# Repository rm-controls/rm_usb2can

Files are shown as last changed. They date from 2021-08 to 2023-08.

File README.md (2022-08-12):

# rm_usb2can

&nbsp;&nbsp;&nbsp;&nbsp;

English/[中文](https://github.com/rm-controls/rm_usb2can/blob/main/README_CN.md)

***

### Brief Introduction

&nbsp;&nbsp;&nbsp;&nbsp;The purpose of this project is to provide [Intel® NUC](https://www.intel.com/content/www/us/en/products/details/nuc.html) and other x86 device with a CAN (Controller Area Network) peripheral interface. Since NUC and most x86 device does not have simple peripheral interfaces such as SPI (Serial Peripheral Interface), it is impossible to use SPI to can chips such as MCP2515. Therefore, the project is developed based on the open source solution [candleLight](https://github.com/candle-usb/candleLight_fw/tree/master) on GitHub, and STM32F072CBT6 is used as the main control chip to realize the function of USB (Universal Serial Bus) to can. STM32F072CBT6 has USB full speed peripherals and can peripherals that can work at the same time. It is packaged as QFP64 (Quad Flat Package) and is an excellent solution.The following figure shows the physical connection between Intel NUC and usb2can.

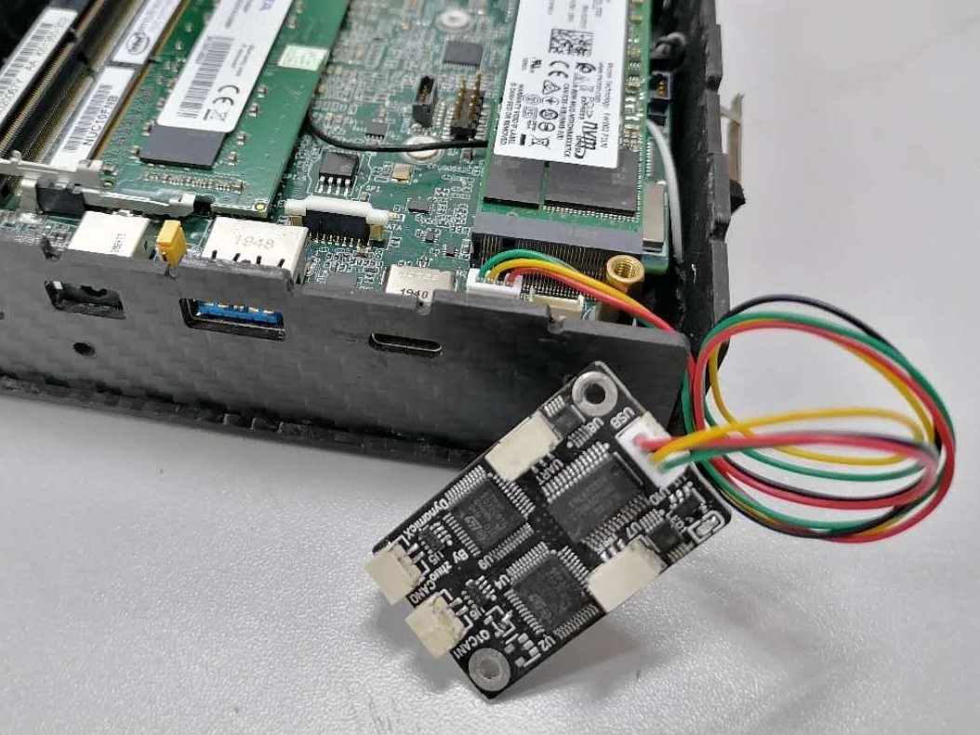
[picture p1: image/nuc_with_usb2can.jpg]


***

### Develop Tools

+ EDA Tool: Altium Designer 20.0.13
+ Compiler: gcc-arm-none-eabi  8-2019-q3-update
+ Programming Tool: STM32CubeProgrammer v2.6.0

***

### Directory Structure

+ bom: three different versions of usb2can material forms.
+ candlelight: the repository of GitHub's open source solution [candleLight](https://github.com/candle-usb/candleLight_fw/tree/master).
+ circuit: circuit schematic diagram and PCB source file designed with Altium designer.
+ gerber: three different versions of usb2can manufacturing documents.
+ image: picture in readme.
+ firmware.bin: Compiled program binaries.

**Note: the PCB and schematic diagram under the circuit folder are example circuits, which are directly used to manufacture products with production results other than those shown in the figure. If you want to directly reproduce the graphic version, please use the production file under the gerber folder.**

***

### Circuit Design

#### Key Points Of Schematic Design

&nbsp;&nbsp;&nbsp;&nbsp;USB HUB Circuit Design: since the whole vehicle needs at least two can buses to ensure the integrity of the data packet returned by the motor, we use GL850G as the USB HUB chip to realize the scheme of USB one driving four. In addition, we also use Schmidt trigger to realize the power on sequence to ensure that the enumeration sequence of USB devices is consistent after each power on.

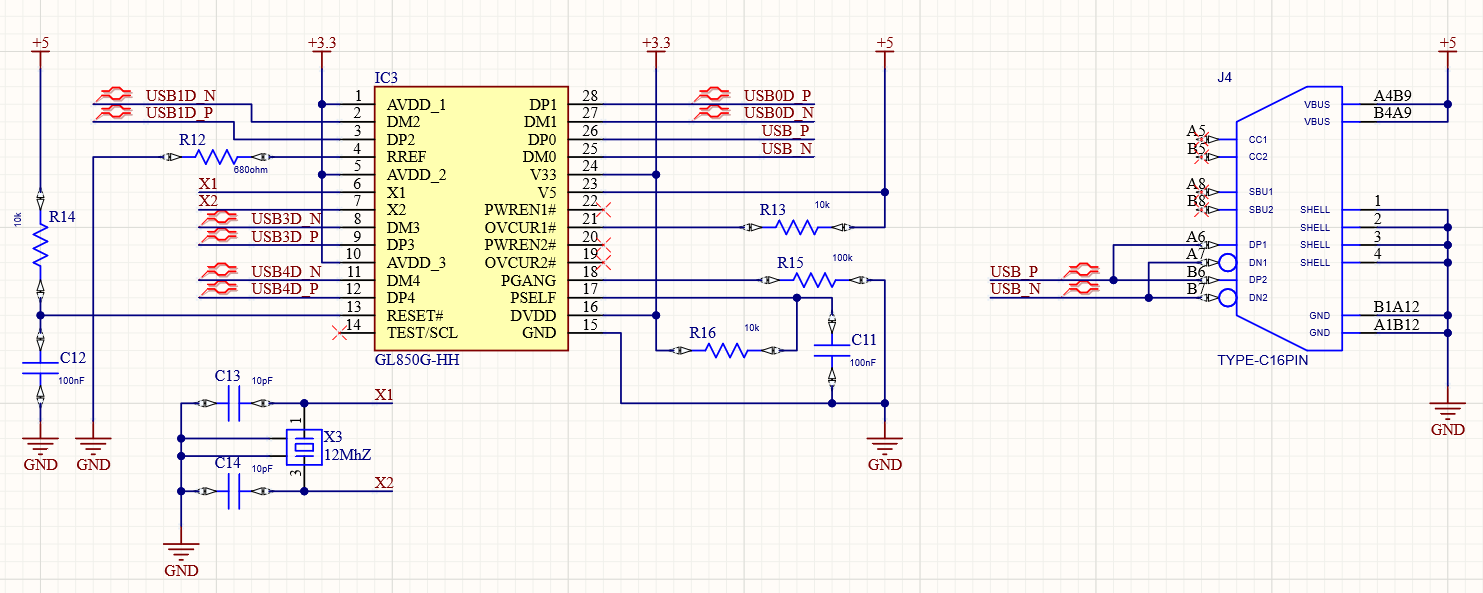
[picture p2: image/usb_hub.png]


&nbsp;&nbsp;&nbsp;&nbsp;USB To CAN Circuit Design: use STM32F072CBT6 to realize the function of USB to can. The can level conversion chip adopts MAX3051EKA chip, which uses 3.3V power supply and is packaged as SOT23-8 (Small Outline Transistor), which provides the basis for PCB miniaturization. The purpose of R6 and R7 resistors in the figure is to change the boot mode of STM32, so that STM32 can switch between DFU (Device Firmware Upgrade) burning mode and flash mode by changing the short circuit mode of R6 and R7, so as to facilitate firmware burning.

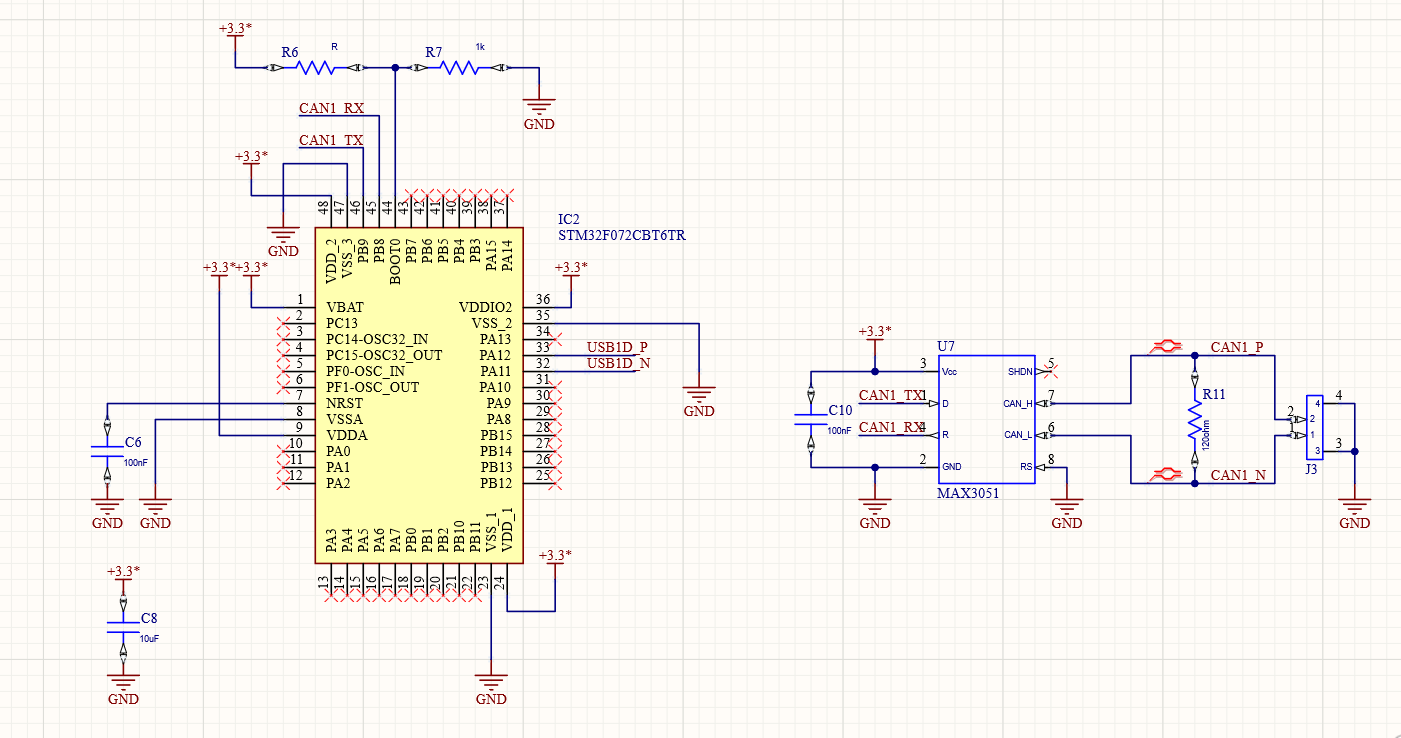
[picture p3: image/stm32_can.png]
stm32_can


#### Key Points Of PCB Layout And Wiring

1. All USB buses need to be set as differential pairs, and the wiring rules of differential signals shall be strictly followed during wiring.
2. All CAN buses need to be set as differential pairs, and the wiring rules of differential signals shall be strictly followed during wiring.
3. The bottom of crystal oscillator and resonant capacitor should be hollowed out without copper.
4. The power line width shall be greater than 0.3mm as far as possible to ensure that the power track does not collapse.

***

### Circuit Making

&nbsp;&nbsp;&nbsp;&nbsp;We provide three different versions of Gerber files for production: [two-way CAN + UART + DBUS](https://github.com/rm-controls/rm_usb2can/tree/main/gerber/2CAN%2BUART%2BDBUS), [four-way CAN](https://github.com/rm-controls/rm_usb2can/tree/main/gerber/4CAN), [UART + DBUS](https://github.com/rm-controls/rm_usb2can/tree/main/gerber/UART%2BDBUS).The circuits of these three versions are designed with two-layer PCB, with an area of about 20 * 30MM. You can directly submit the packaged Gerber file to a manufacturer (such as [jlc](https://www.jlc.com/#)) for production.

&nbsp;&nbsp;&nbsp;&nbsp;You can find the BOM (Bill Of Material) table corresponding to the board [here](https://github.com/rm-controls/rm_usb2can/tree/main/bom) and weld the components to the fabricated PCB according to this table. After welding, please carefully check whether there is residual solder between the pins, which will lead to short circuit of the circuit board. At the same time, you should also check whether there is false soldering of the pins.

&nbsp;&nbsp;&nbsp;&nbsp;After welding, use a multimeter to check whether there is a short circuit between 5V power interface and GND, and whether there is a short circuit between 3.3V power output and GND. When the above situation does not occur, connect the board to the USB port of the computer. At this time, you should see that the power indicator on the board is on, and the computer can recognize the USB HUB chip.

**Note: do not weld the up / down resistance used to switch STM32 download mode at the same time, as it may cause a short circuit between the power supply and GND!**

***

### Firmware Programming

&nbsp;&nbsp;&nbsp;&nbsp;You can [click here](https://github.com/rm-controls/rm_usb2can/releases/download/firmware_v1_0/candleLight.bin) to download the compiled firmware, or follow the [candlelight documentation](https://github.com/candle-usb/candleLight_fw/tree/master#building) to compile firmware by yourself. Finally, you will get the .bin file. We use [STM32CubeProgrammer](https://www.st.com/en/development-tools/stm32cubeprog.html) to burn the firmware into STM32 through USB. The steps to download firmware are shown below:

1. Remove the pull-down resistance of BOOT0 pin of STM32 and weld the pull-up resistance.
2. Connect the board to the USB port of the computer and open STM32CubeProgrammer.
3. Click the three buttons shown in the following figure in STM32CubeProgrammer to search for available STM32 devices.

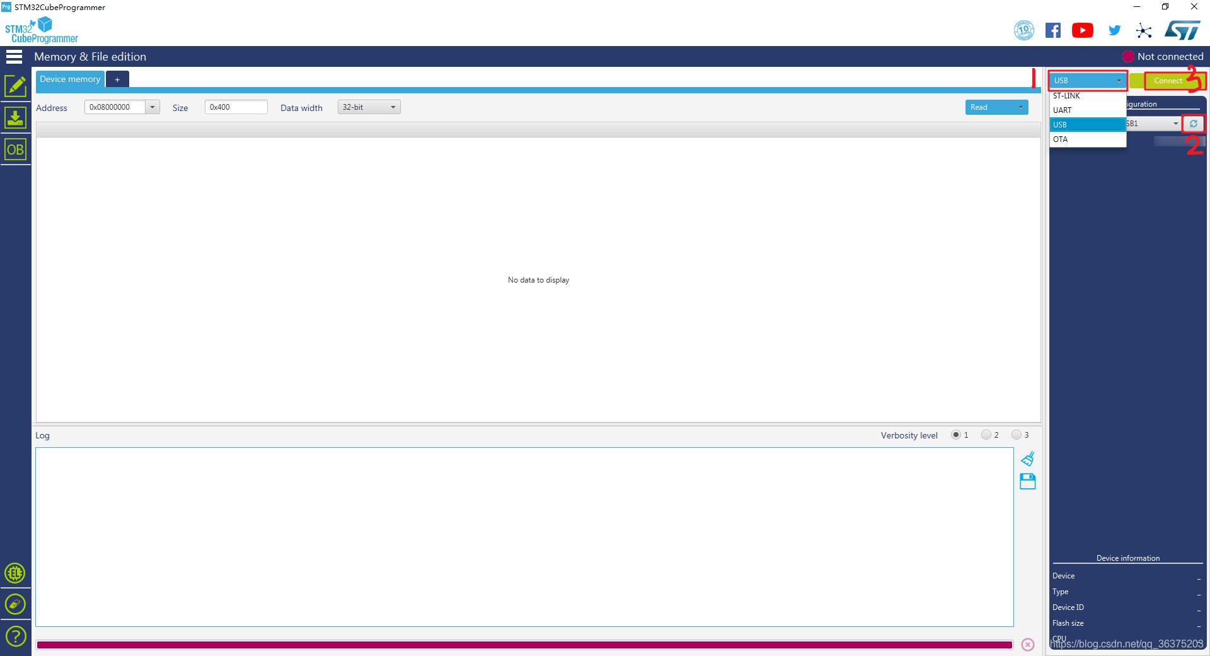
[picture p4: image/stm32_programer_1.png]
stm32_programer_1


4. After successful connection, click the "Read" button to read the firmware and select the prepared firmware.

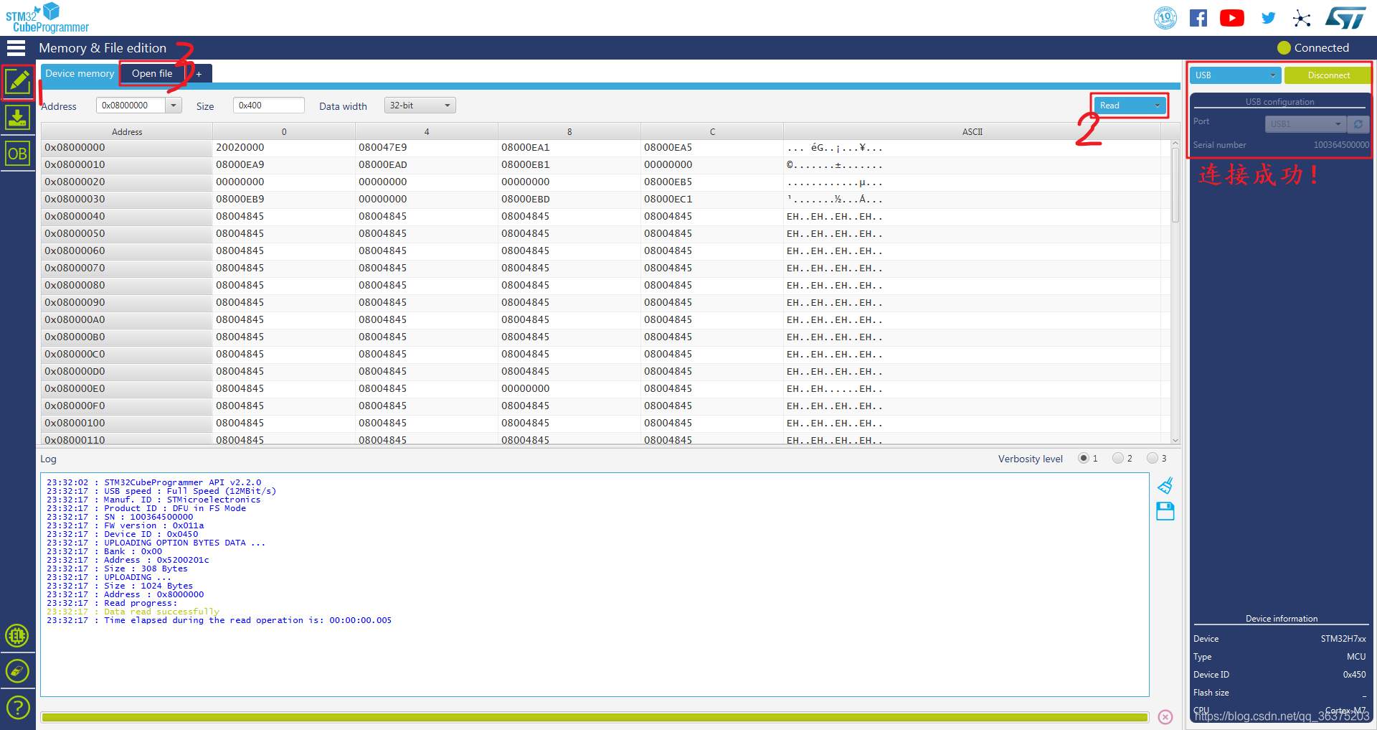
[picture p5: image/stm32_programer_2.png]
stm32_programer_2


5. Click "Download" to download the firmware. After the download is successful, you can see the successful information.

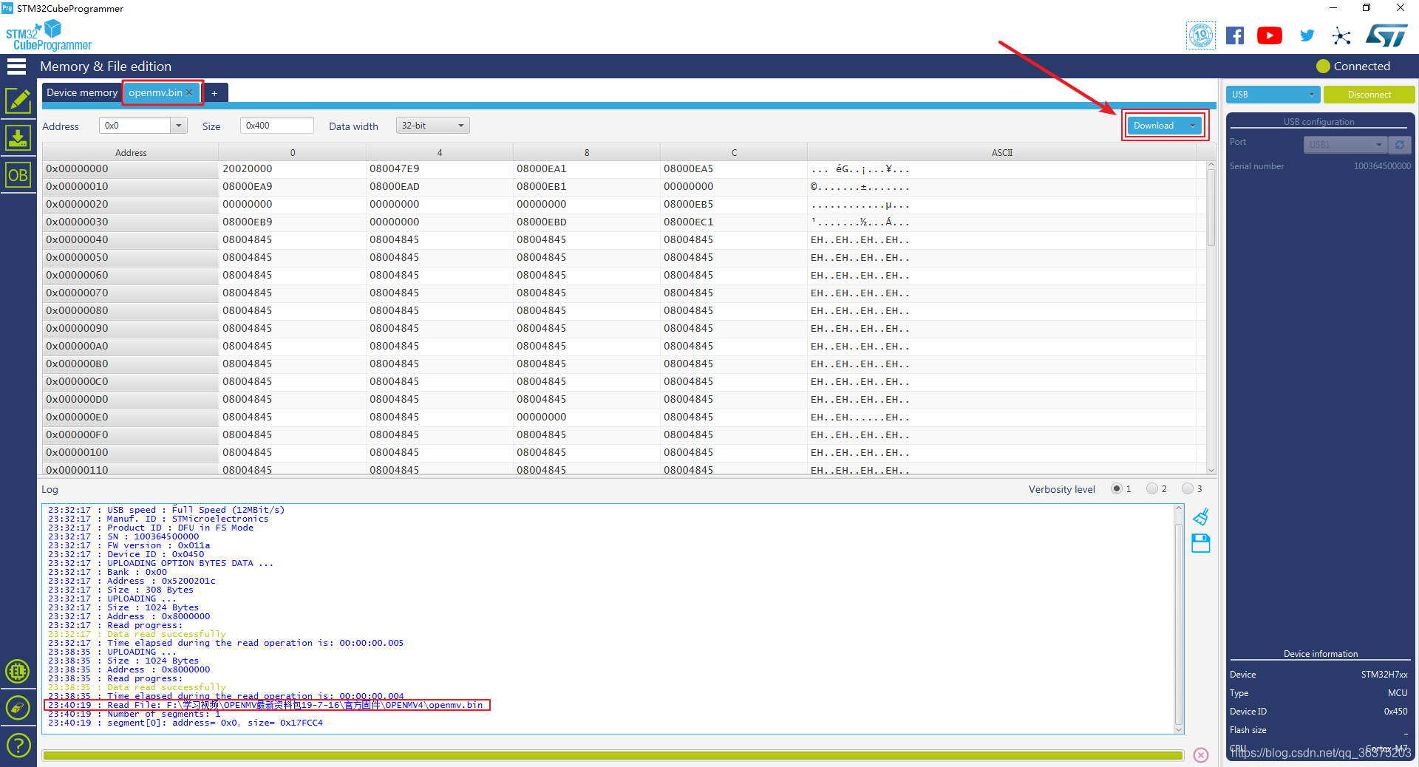
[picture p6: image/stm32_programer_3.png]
stm32_programer_3


6. Remove the pull-up resistance of BOOT0 pin on STM32 and weld the pull-down resistance. Power on again at this time, and the firmware will start running on STM32.

***

### Test Features On Ubuntu

1. Install dependent packages:

```bash
$ sudo apt-get update && sudo apt-get -y upgrade
$ sudo apt-get install -y can-utils net-tools
```

2. Check whether can device is detected:

```bash
$ ifconfig -a
# If a device with can name is found in the list, it means that the device can be recognized
```

3. Connect the two can ports with a **straight line** to facilitate loop back test.
4. Initialize CAN0 and CAN1 devices with a bit rate of 1Mbits:

```bash
$ sudo ip link set can0 up type can bitrate 1000000
$ sudo ip link set can1 up type can bitrate 1000000
```

5. Open a new terminal to monitor the information received by can0:

```bash
$ candump can0
```

6. Sending information using can1 in a terminal:

```bash
$ cansend can1 200#5A5A5A5A5A5A5A5A
```

If you can see the following information from can1 in the terminal monitoring can0, it indicates that the communication is successful and the module works normally.

```bash
can0 200 [8] 5A 5A 5A 5A 5A 5A 5A 5A
```

***

### License

The source code is released under a [MIT License](https://github.com/rm-controls/rm_usb2can/blob/main/LICENSE).

**Affiliation：DynamicX<br>
Maintainer：YanzhenZhu, 2208213223@qq.com**

The product has been tested under Ubuntu 18.04 and 20.04. This is research code, expect that it changes often and any fitness for a particular purpose is disclaimed.

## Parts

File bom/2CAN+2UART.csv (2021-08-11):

ID | Name | Designator | Footprint | Quantity | Manufacturer Part | Manufacturer | Supplier | Supplier Part | Price | Pins
1 | 10uF | C1,C2,C3,C4,C20 | C0402 | 5 | CL05A106MQ5NUNC | SAMSUNG | LCSC | C15525 | 0.044 | 2
2 | 100nF | C5,C6,C7,C8,C9,C10,C11,C12,C13,C14,C15,C16,C17,C18,C21,C23 | C0402 | 16 | CL05B104KO5NNNC | SAMSUNG | LCSC | C1525 | 0.0071 | 2
3 | 18pF | C19,C22 | C0402 | 2 | 0402CG180J500NT | FH | LCSC | C1549 | 0.0079 | 2
4 | GH1.25_2P | CAN1,CAN2 | GH1.25_2P_卧贴 | 2 |  | Changjiang Connectors | LCSC | C225125 | 0.4487 | 2
5 | PESD5V0F1BL,315 | D1,D2,D3,D4,D6,D7,D8 | SOD-882_L1.0-W0.6-BI | 7 | PESD5V0F1BL,315 | Nexperia | LCSC | C45961 | 0.2763 | 2
6 | PESD12V0F1BL,315 | D5 | SOD-882_L1.0-W0.6-BI | 1 | PESD5V0F1BL,315 | Nexperia | LCSC | C45961 | 0.2763 | 2
7 | ESDR0502NMUTBG | D9 | UDFN-6_L1.2-W1.0-P0.40-BL | 1 | ESDR0502NMUTBG | ON Semicon | LCSC | C327480 | 0.99 | 6
8 | GH1.25-3P-COLOR | DBUS,UART | GH1.25-3P-COLOR | 2 | A2008WR-S-3P | Changjiang Connectors | LCSC | C273131 | 0.751 | 5
9 | 19-217/BHC-ZL1M2RY/3T | LED1 | LED0603-R-RD | 1 | 19-217/BHC-ZL1M2RY/3T | EVERLIGHT | LCSC | C72041 | 0.0992 | 2
10 | m2.5 | M1,M2 | M2.5 螺丝 | 2
11 | AO3400A | Q1,Q2 | SOT-23-3_L2.9-W1.6-P1.90-LS2.8-BR | 2 | AO3400A | AOS | LCSC | C20917 | 1.185 | 3
12 | S8050_C2146 | Q3 | SOT-23-3_L3.0-W1.7-P0.95-LS2.9-BR | 1 | S8050 | CJ | LCSC | C2146 | 0.1411 | 3
13 | 10K | R1,R2,R3,R10,R15,R16,R18 | R0402 | 7 | 0402WGF1002TCE | UniOhm | LCSC | C25744 | 0.004 | 2
14 | 0 | R4,R11 | R0402 | 2 | 0402WGF0000TCE | UniOhm | LCSC | C17168 | 0.0046 | 2
15 | 10k | R5,R13 | R0402 | 2 | 0402WGF0000TCE | UniOhm | LCSC | C17168 | 0.0046 | 2
16 | 1K | R6 | R0402 | 1 | 0402WGF1001TCE | UniOhm | LCSC | C11702 | 0.0042 | 2
17 | 120 | R7,R8 | R0402 | 2 | 0402WGF1200TCE | UniOhm | LCSC | C25079 | 0.0045 | 2
18 | 4.7K | R9 | R0402 | 1 | 0402WGF4701TCE | UniOhm | LCSC | C25900 | 0.0038 | 2
19 | 47K | R12 | R0402 | 1 | 0402WGF4702TCE | UniOhm | LCSC | C25792 | 0.0046 | 2
20 | 680 | R14 | R0402 | 1 | 0402WGF6800TCE | UniOhm | LCSC | C25130 | 0.0038 | 2
21 | 100K | R17 | R0402 | 1 | 0402WGF1003TCE | UniOhm | LCSC | C25741 | 0.004 | 2
22 | 0R | R19 | R0402 | 1 | 0402WGF6800TCE | UniOhm | LCSC | C25130 | 0.0038 | 2
23 | HX9193-33GB | U1 | SOT-23-5_L3.0-W1.7-P0.95-LS2.8-BR | 1 | HX9193-33GB | hengjiaxing | LCSC | C296123 | 0.1654 | 4
24 | 74LVC1G17 | U2,U3 | SOT-23-5 | 2 |  |  |  |  |  | 4
25 | STM32F072CBT6 | U4,U9 | LQFP-48_L7.0-W7.0-P0.50-LS9.0-BL | 2 | STM32F072CBT6 | STMicroelectronics | LCSC | C81720 | 144.77 | 15
26 | MAX3051EKA+T | U5,U6 | SOT-23-8_L3.0-W1.7-P0.65-LS2.8-TL | 2 | MAX3051EKA+T | MAXIM | LCSC | C112005 | 9.59 | 7
27 | CH340E | U7 | MSOP-10_L3.0-W3.0-P0.50-LS5.0-BL | 1 | CH340E | WCH | LCSC | C99652 | 3.7 | 6
28 | CH340E | U8 | MSOP-10_L3.0-W3.0-P0.50-LS5.0-BL | 1 | CH340E | WCH | LCSC | C99652 | 3.7 | 7
29 | GL850G-HHY22 | U10 | SSOP-28_L10.2-W5.3-P0.65-LS7.8-BL | 1 | GL850G-HHY22 | GENESYS | LCSC | C136617 | 5.23 | 24
30 | MX1.25-4P | USB | MX1.25-4P | 1 |  |  |  |  |  | 4
31 | 12MHz | X1 | OSC-SMD_4P-L3.2-W2.5-BL | 1 | X322512MSB4SI | YXC | LCSC | C9002 | 0.59 | 4

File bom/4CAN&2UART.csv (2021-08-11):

Comment | Description | Designator | Footprint | Quantity | value
C | 无极性贴片电容 | C1, C2, C3, C4, C11, C18, C19, C20 | C 0402_L | 8 | 10uF
C | 无极性贴片电容 | C5, C6, C7, C8, C12, C13, C14, C17, C21, C22, C23, C24, C25, C26, C27, C28, C29, C30, C31, C32, C33, C34, C35, C36, C37, C38, C39, C40, C41, C42, C43, C44 | C 0402_L | 32 | 100nF
C | 无极性贴片电容 | C9, C10 | C 0402_L | 2 | 18pF
C | 无极性贴片电容 | C15, C16 | C 0402_L | 2 | 10pF
GH1.25-2P | 2P接插件 | CAN1, CAN2, CAN3, CAN4 | GH1.25-2P | 4
ESDR0502NMUTBG | USB2.0 ESD保护 | D1, D7 | UDFN-6 | 2
LED-SMD | 贴片LED | D2, D8 | LED 0603R | 2
PESD12VV1BL | 双向ESD，5V关断电压 | D3 | SOD-882 | 1
PESD5V0F1BL | 双向ESD，5V关断电压 | D4, D5, D6, D9, D10, D11, D12, D13, D14, D15, D16 | SOD-882 | 11
GH1.25-3P | 3P接插件 | J1, J2 | GH1.25-3P | 2
M2.5 | 铜柱孔 | M1, M2, M3, M4, M5, M6 | M3 125X200 | 6
AO3400A | N沟道MOS管 | Q1, Q3, Q4, Q5 | SOT23-3N | 4
S8050 | 高频放大-NPN型 | Q2 | SOT23-3N | 1
R | 贴片电阻 | R1, R5, R7, R8, R12, R14, R15, R16, R22, R23, R30, R31 | R 0402_L | 12 | 10k
R | 贴片电阻 | R2, R10 | R 0402_L | 2 | 1k
R | 贴片电阻 | R3, R11 | R 0402_L | 2 | 680R
R | 贴片电阻 | R4 | R 0402_L | 1 | 4.7k
R | 贴片电阻 | R6, R13 | R 0402_L | 2 | 100k
R | 贴片电阻 | R9 | R 0402_L | 1 | 47k
R | 贴片电阻 | R17 | R 0402_L | 1 | 51k
R | 贴片电阻 | R18 | R 0402_L | 1 | 270k
R | 贴片电阻 | R19, R26, R27, R34 | R 0402_L | 4 | 120R
R | 贴片电阻 | R20, R21, R24, R25, R28, R29, R32, R33 | R 0402_L | 8 | 0R
HX9193-33G | LDO 3V3 | U1, U6 | SOT23-5N | 2
74LVC1G17 |  | U2, U8, U9, U10 | SOT23-5N | 4
GL850G | USB-HUB 1拖4 | U3, U7 | SSOP28_N | 2
CH340E | USB转串口 | U4, U5 | MSOP10_N | 2
MAX3051 | CAN收发器 | U11, U14, U15, U18 | SOT23-8N | 4
STM32F072CBT6 |  | U12, U13, U16, U17 | LQFP48 7X7_N | 4
MX1.25-4P | 4P接插件 | USB, USB1 | MX 1.25-WI-4P | 2
12M | 4脚无源晶振 | X1, X2 | OSC 3225-4P | 2

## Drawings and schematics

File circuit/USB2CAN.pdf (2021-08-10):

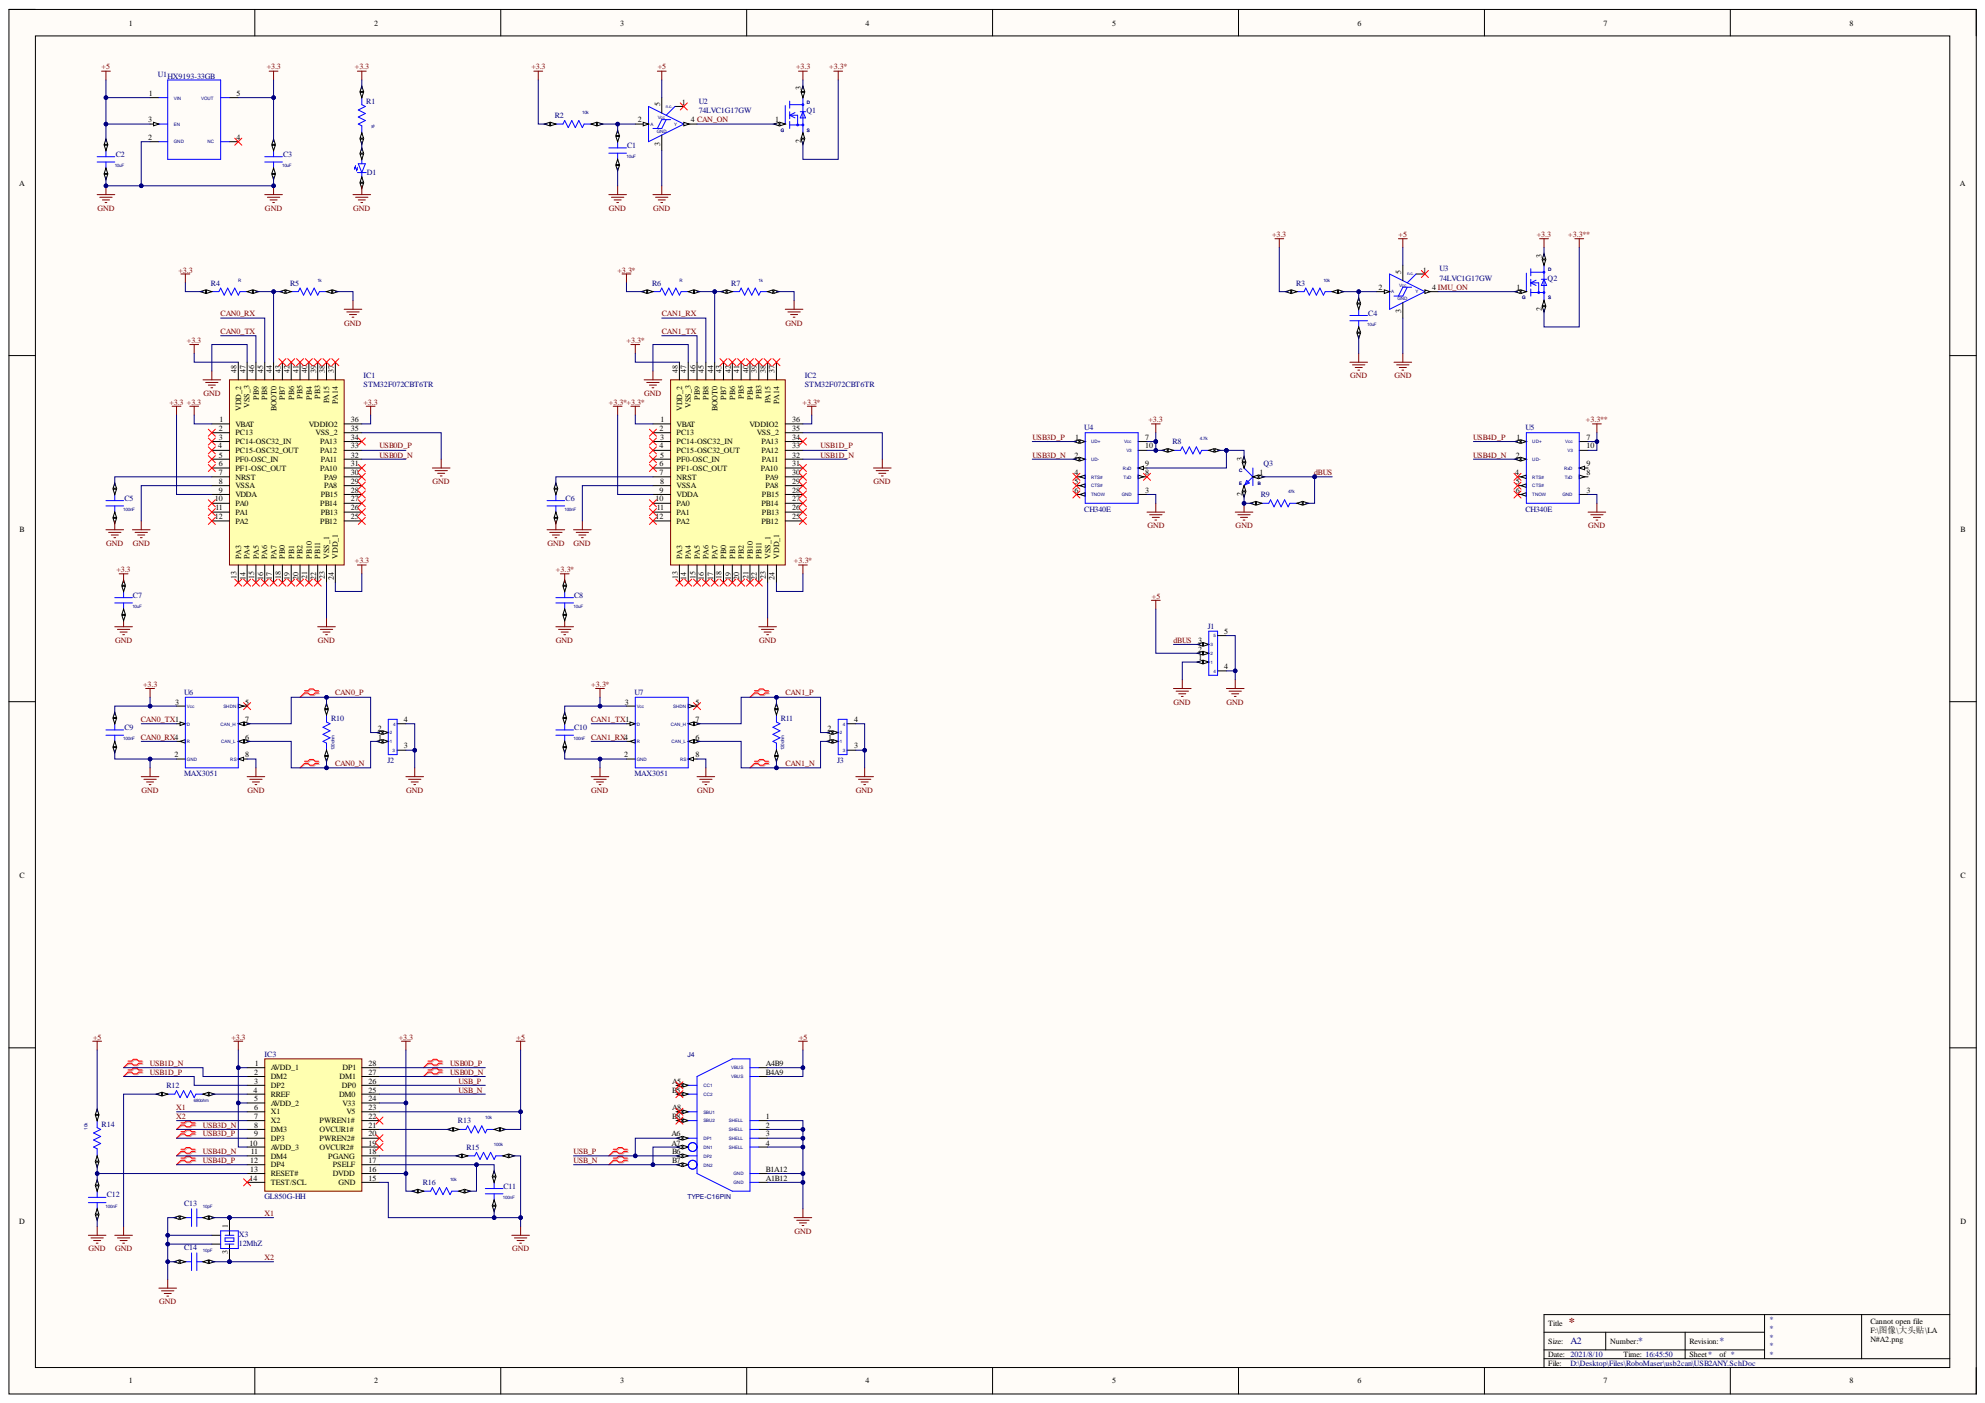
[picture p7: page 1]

D:\Desktop\Files\RoboMaser\usb2can\USB2ANY.SchDoc

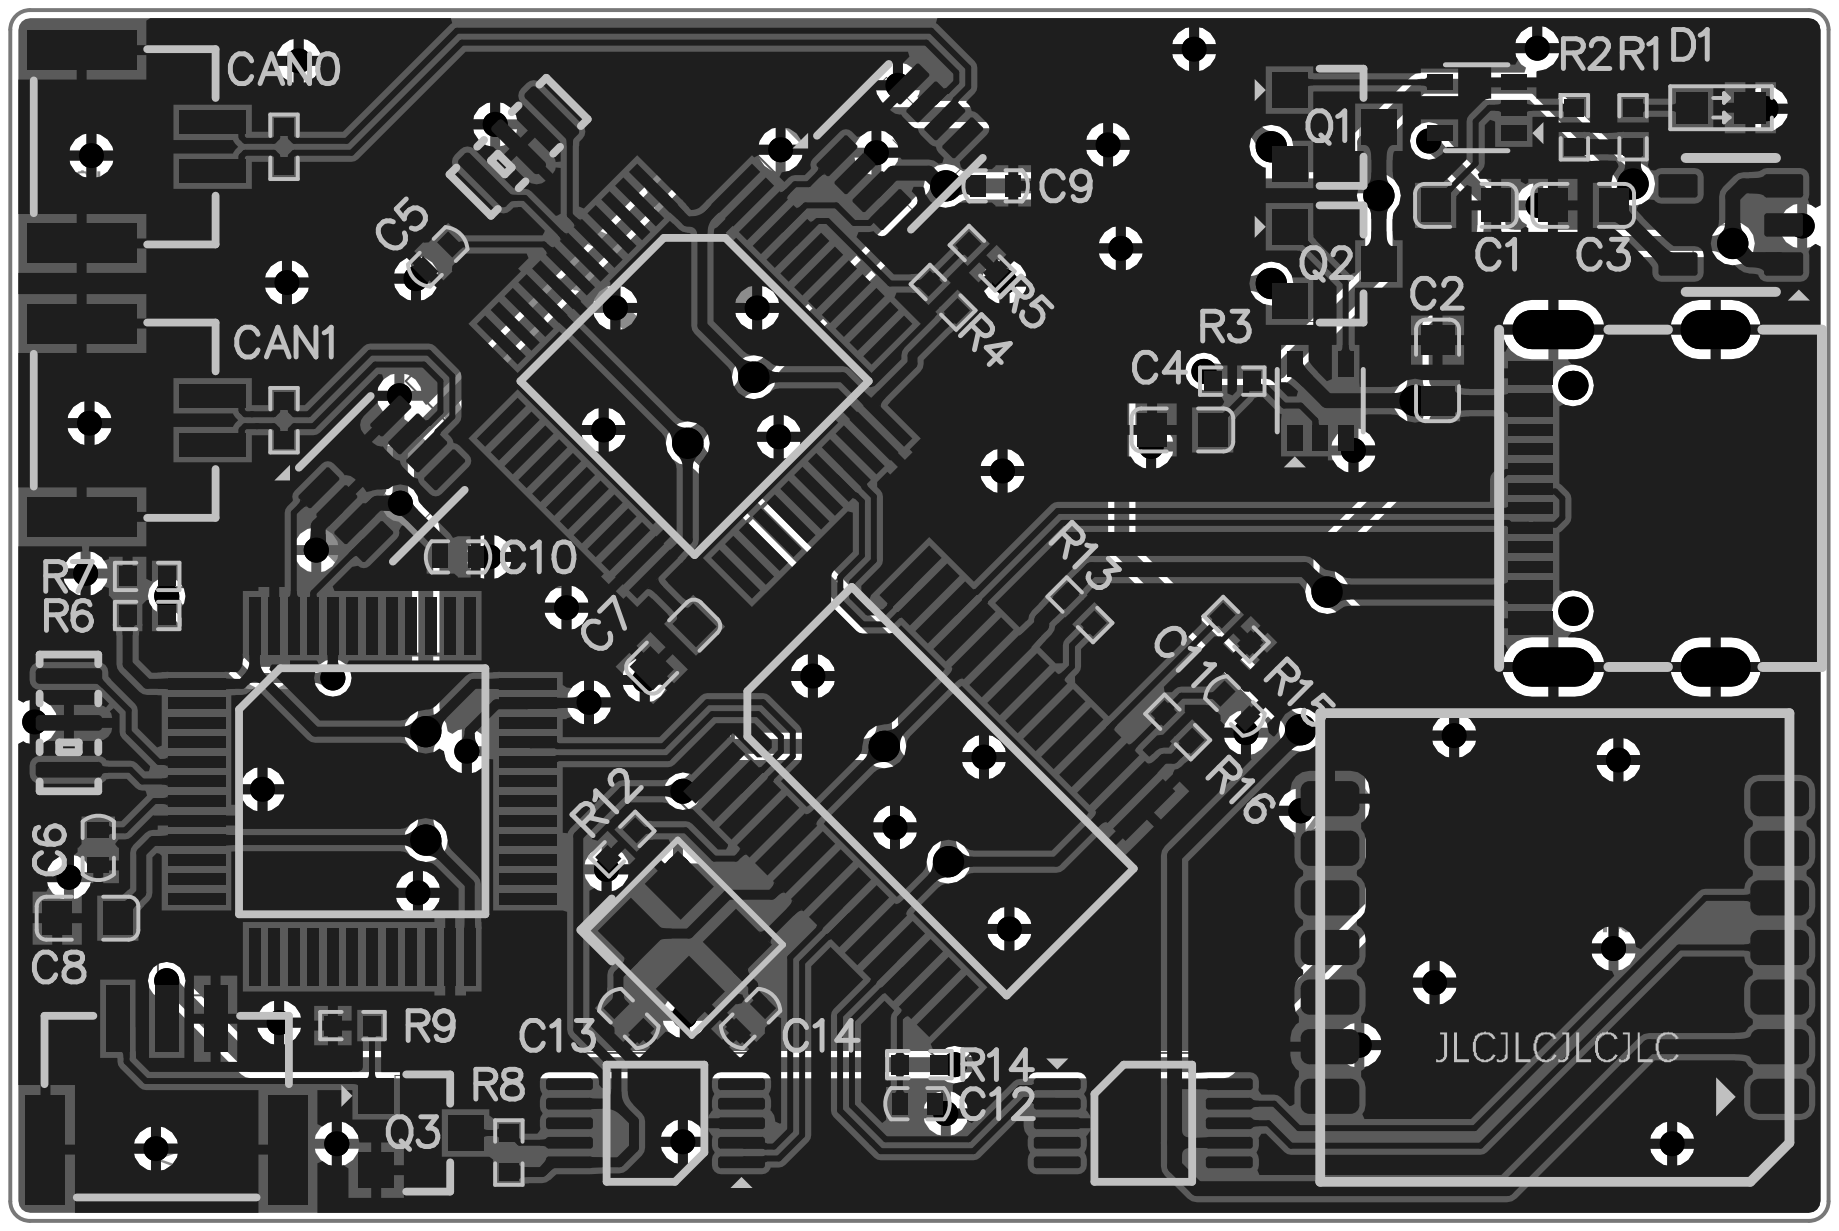
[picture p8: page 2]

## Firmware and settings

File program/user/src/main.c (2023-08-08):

/*

The MIT License (MIT)

Copyright (c) 2016 Hubert Denkmair

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
*/

#include <stdlib.h>
#include "config.h"
#include "hal_include.h"
#include "usbd_def.h"
#include "usbd_desc.h"
#include "usbd_core.h"
#include "usbd_gs_can.h"
#include "gpio.h"
#include "queue.h"
#include "gs_usb.h"
#include "can.h"
#include "led.h"
#include "dfu.h"
#include "timer.h"
#include "flash.h"
#include "util.h"

void SystemClock_Config(void);
static bool send_to_host_or_enqueue(struct gs_host_frame *frame);
static void send_to_host();

can_data_t hCAN = {0};
USBD_HandleTypeDef hUSB = {0};
led_data_t hLED = {0};

queue_t *q_frame_pool = NULL;
queue_t *q_from_host = NULL;
queue_t *q_to_host = NULL;

uint32_t received_count = 0;

int main(void) {
    uint32_t last_can_error_status = 0;

    HAL_Init();
    SystemClock_Config();
    flash_load();
    gpio_init();
    led_init(&hLED, LED1_GPIO_Port, LED1_Pin, LED1_Active_High, LED2_GPIO_Port, LED2_Pin, LED2_Active_High);

    /* nice wake-up pattern */
    for (uint8_t i = 0; i < 10; i++) {
        HAL_GPIO_TogglePin(LED1_GPIO_Port, LED1_Pin);
        HAL_Delay(50);
        HAL_GPIO_TogglePin(LED2_GPIO_Port, LED2_Pin);
    }

    led_set_mode(&hLED, led_mode_off);
    timer_init();

    can_init(&hCAN, CAN_INTERFACE);
    can_disable(&hCAN);

    q_frame_pool = queue_create(CAN_QUEUE_SIZE);
    q_from_host = queue_create(CAN_QUEUE_SIZE);
    q_to_host = queue_create(CAN_QUEUE_SIZE);
    assert_basic(q_frame_pool && q_from_host && q_to_host);

    struct gs_host_frame *msgbuf = calloc(CAN_QUEUE_SIZE, sizeof(struct gs_host_frame));
    assert_basic(msgbuf);

    for (unsigned i = 0; i < CAN_QUEUE_SIZE; i++) {
        queue_push_back(q_frame_pool, &msgbuf[i]);
    }

    USBD_Init(&hUSB, (USBD_DescriptorsTypeDef *) &FS_Desc, DEVICE_FS);
    USBD_RegisterClass(&hUSB, &USBD_GS_CAN);
    USBD_GS_CAN_Init(&hUSB, q_frame_pool, q_from_host, &hLED);
    USBD_GS_CAN_SetChannel(&hUSB, 0, &hCAN);
    USBD_Start(&hUSB);

    while (1) {
        struct gs_host_frame *frame = queue_pop_front(q_from_host);
        if (frame != 0) { // send can message from host
            if (can_send(&hCAN, frame)) {
                // Echo sent frame back to host
                frame->flags = 0x0;
                frame->reserved = 0x0;
                frame->timestamp_us = timer_get();
                send_to_host_or_enqueue(frame);

                led_indicate_trx(&hLED, led_2);
            } else {
                queue_push_front(q_from_host, frame); // retry later
            }
        }

        if (USBD_GS_CAN_TxReady(&hUSB)) {
            send_to_host();
        }

        if (can_is_rx_pending(&hCAN)) {
            struct gs_host_frame *tx_frame = queue_pop_front(q_frame_pool);
            if (tx_frame != 0) {
                if (can_receive(&hCAN, tx_frame)) {
                    received_count++;

                    tx_frame->timestamp_us = timer_get();
                    tx_frame->echo_id = 0xFFFFFFFF; // not a echo frame
                    tx_frame->channel = 0;
                    tx_frame->flags = 0;
                    tx_frame->reserved = 0;

                    send_to_host_or_enqueue(tx_frame);
                    led_indicate_trx(&hLED, led_1);
                } else
                    queue_push_back(q_frame_pool, tx_frame);
            }
            // If there are frames to receive, don't report any error frames. The
            // best we can localize the errors to is "after the last successfully
            // received frame", so wait until we get there. LEC will hold some error
            // to report even if multiple pass by.
        } else {
            uint32_t can_err = can_get_error_status(&hCAN);
            struct gs_host_frame *err_frame = queue_pop_front(q_frame_pool);
            if (err_frame != 0) {
                err_frame->timestamp_us = timer_get();
                if (can_parse_error_status(can_err, last_can_error_status, &hCAN, err_frame)) {
                    send_to_host_or_enqueue(err_frame);
                    last_can_error_status = can_err;
                } else
                    queue_push_back(q_frame_pool, err_frame);
            }
        }

        led_update(&hLED);

        if (USBD_GS_CAN_DfuDetachRequested(&hUSB)) {
            dfu_run_bootloader();
        }

    }
}

void HAL_MspInit(void) {
    __HAL_RCC_SYSCFG_CLK_ENABLE();
    HAL_NVIC_SetPriority(SysTick_IRQn, 0, 0);
}

void SystemClock_Config(void) {
    RCC_OscInitTypeDef RCC_OscInitStruct;
    RCC_ClkInitTypeDef RCC_ClkInitStruct;

    RCC_PeriphCLKInitTypeDef PeriphClkInit;
    RCC_CRSInitTypeDef RCC_CRSInitStruct;

    RCC_OscInitStruct.OscillatorType = RCC_OSCILLATORTYPE_HSI48;
    RCC_OscInitStruct.HSI48State = RCC_HSI48_ON;
    RCC_OscInitStruct.PLL.PLLState = RCC_PLL_NONE;
    HAL_RCC_OscConfig(&RCC_OscInitStruct);

    RCC_ClkInitStruct.ClockType = RCC_CLOCKTYPE_HCLK | RCC_CLOCKTYPE_SYSCLK | RCC_CLOCKTYPE_PCLK1;
    RCC_ClkInitStruct.SYSCLKSource = RCC_SYSCLKSOURCE_HSI48;
    RCC_ClkInitStruct.AHBCLKDivider = RCC_SYSCLK_DIV1;
    RCC_ClkInitStruct.APB1CLKDivider = RCC_HCLK_DIV1;
    HAL_RCC_ClockConfig(&RCC_ClkInitStruct, FLASH_LATENCY_1);

    PeriphClkInit.PeriphClockSelection = RCC_PERIPHCLK_USB;
    PeriphClkInit.UsbClockSelection = RCC_USBCLKSOURCE_HSI48;
    HAL_RCCEx_PeriphCLKConfig(&PeriphClkInit);

    __HAL_RCC_CRS_CLK_ENABLE();
    RCC_CRSInitStruct.Prescaler = RCC_CRS_SYNC_DIV1;
    RCC_CRSInitStruct.Source = RCC_CRS_SYNC_SOURCE_USB;
    RCC_CRSInitStruct.Polarity = RCC_CRS_SYNC_POLARITY_RISING;
    RCC_CRSInitStruct.ReloadValue = __HAL_RCC_CRS_RELOADVALUE_CALCULATE(48000000, 1000);
    RCC_CRSInitStruct.ErrorLimitValue = 34;
    RCC_CRSInitStruct.HSI48CalibrationValue = 32;
    HAL_RCCEx_CRSConfig(&RCC_CRSInitStruct);

    HAL_SYSTICK_Config(HAL_RCC_GetHCLKFreq() / 1000);
    HAL_SYSTICK_CLKSourceConfig(SYSTICK_CLKSOURCE_HCLK);

    /* SysTick_IRQn interrupt configuration */
    HAL_NVIC_SetPriority(SysTick_IRQn, 0, 0);
}

bool send_to_host_or_enqueue(struct gs_host_frame *frame) {
    queue_push_back(q_to_host, frame);
    return true;
}

void send_to_host() {
    struct gs_host_frame *frame = queue_pop_front(q_to_host);

    if (!frame)
        return;

    if (USBD_GS_CAN_SendFrame(&hUSB, frame) == USBD_OK)
        queue_push_back(q_frame_pool, frame);
    else
        queue_push_front(q_to_host, frame);
}

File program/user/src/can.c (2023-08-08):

/*

The MIT License (MIT)

Copyright (c) 2016 Hubert Denkmair

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
*/

#include "can.h"

void can_init(can_data_t *hcan, CAN_TypeDef *instance) {
    __HAL_RCC_CAN1_CLK_ENABLE();

    GPIO_InitTypeDef itd;

    itd.Pin = GPIO_PIN_8 | GPIO_PIN_9;
    itd.Mode = GPIO_MODE_AF_PP;
    itd.Pull = GPIO_NOPULL;
    itd.Speed = GPIO_SPEED_FREQ_HIGH;
    itd.Alternate = GPIO_AF4_CAN;
    HAL_GPIO_Init(GPIOB, &itd);

    hcan->instance = instance;
    hcan->brp = 6;
    hcan->sjw = 1;

    hcan->phase_seg1 = 13;
    hcan->phase_seg2 = 2;
}

bool can_set_bittiming(can_data_t *hcan, uint16_t brp, uint8_t phase_seg1, uint8_t phase_seg2, uint8_t sjw) {
    if ((brp > 0) && (brp <= 1024)
        && (phase_seg1 > 0) && (phase_seg1 <= 16)
        && (phase_seg2 > 0) && (phase_seg2 <= 8)
        && (sjw > 0) && (sjw <= 4)
        ) {
        hcan->brp = brp & 0x3FF;
        hcan->phase_seg1 = phase_seg1;
        hcan->phase_seg2 = phase_seg2;
        hcan->sjw = sjw;
        return true;
    } else {
        return false;
    }
}

void can_enable(can_data_t *hcan, bool loop_back, bool listen_only, bool one_shot) {
    (void) one_shot;
    CAN_TypeDef *can = hcan->instance;

    uint32_t mcr = CAN_MCR_INRQ
        | CAN_MCR_ABOM
        | CAN_MCR_AWUM
        | CAN_MCR_TXFP
        | CAN_MCR_NART;

    uint32_t btr = ((uint32_t) (hcan->sjw - 1)) << 24
        | ((uint32_t) (hcan->phase_seg1 - 1)) << 16
        | ((uint32_t) (hcan->phase_seg2 - 1)) << 20
        | (hcan->brp - 1)
        | (loop_back ? CAN_MODE_LOOPBACK : 0)
        | (listen_only ? CAN_MODE_SILENT : 0);


    // Reset CAN peripheral
    can->MCR |= CAN_MCR_RESET;
    while ((can->MCR & CAN_MCR_RESET) != 0); // reset bit is set to zero after reset
    while ((can->MSR & CAN_MSR_SLAK) == 0);  // should be in sleep mode after reset

    can->MCR |= CAN_MCR_INRQ;
    while ((can->MSR & CAN_MSR_INAK) == 0);

    can->MCR = mcr;
    can->BTR = btr;

    can->MCR &= ~CAN_MCR_INRQ;
    while ((can->MSR & CAN_MSR_INAK) != 0);

    uint32_t filter_bit = 0x00000001;
    can->FMR |= CAN_FMR_FINIT;
    can->FMR &= ~CAN_FMR_CAN2SB;
    can->FA1R &= ~filter_bit;        // disable filter
    can->FS1R |= filter_bit;         // set to single 32-bit filter mode
    can->FM1R &= ~filter_bit;        // set filter mask mode for filter 0
    can->sFilterRegister[0].FR1 = 0; // filter ID = 0
    can->sFilterRegister[0].FR2 = 0; // filter Mask = 0
    can->FFA1R &= ~filter_bit;       // assign filter 0 to FIFO 0
    can->FA1R |= filter_bit;         // enable filter
    can->FMR &= ~CAN_FMR_FINIT;
}

void can_disable(can_data_t *hcan) {
    CAN_TypeDef *can = hcan->instance;
    can->MCR |= CAN_MCR_INRQ; // send can controller into initialization mode
}

bool can_is_enabled(can_data_t *hcan) {
    CAN_TypeDef *can = hcan->instance;
    return (can->MCR & CAN_MCR_INRQ) == 0;
}

bool can_is_rx_pending(can_data_t *hcan) {
    CAN_TypeDef *can = hcan->instance;
    return ((can->RF0R & CAN_RF0R_FMP0) != 0);
}

bool can_receive(can_data_t *hcan, struct gs_host_frame *rx_frame) {
    CAN_TypeDef *can = hcan->instance;

    if (can_is_rx_pending(hcan)) {
        CAN_FIFOMailBox_TypeDef *fifo = &can->sFIFOMailBox[0];

        if (fifo->RIR & CAN_RI0R_IDE) {
            rx_frame->can_id = CAN_EFF_FLAG | ((fifo->RIR >> 3) & 0x1FFFFFFF);
        } else {
            rx_frame->can_id = (fifo->RIR >> 21) & 0x7FF;
        }

        if (fifo->RIR & CAN_RI0R_RTR) {
            rx_frame->can_id |= CAN_RTR_FLAG;
        }

        rx_frame->can_dlc = fifo->RDTR & CAN_RDT0R_DLC;

        rx_frame->data[0] = (fifo->RDLR >> 0) & 0xFF;
        rx_frame->data[1] = (fifo->RDLR >> 8) & 0xFF;
        rx_frame->data[2] = (fifo->RDLR >> 16) & 0xFF;
        rx_frame->data[3] = (fifo->RDLR >> 24) & 0xFF;
        rx_frame->data[4] = (fifo->RDHR >> 0) & 0xFF;
        rx_frame->data[5] = (fifo->RDHR >> 8) & 0xFF;
        rx_frame->data[6] = (fifo->RDHR >> 16) & 0xFF;
        rx_frame->data[7] = (fifo->RDHR >> 24) & 0xFF;

        can->RF0R |= CAN_RF0R_RFOM0; // release FIFO

        return true;
    } else {
        return false;
    }
}

static CAN_TxMailBox_TypeDef *can_find_free_mailbox(can_data_t *hcan) {
    CAN_TypeDef *can = hcan->instance;

    uint32_t tsr = can->TSR;
    if (tsr & CAN_TSR_TME0) {
        return &can->sTxMailBox[0];
    } else if (tsr & CAN_TSR_TME1) {
        return &can->sTxMailBox[1];
    } else if (tsr & CAN_TSR_TME2) {
        return &can->sTxMailBox[2];
    } else {
        return 0;
    }
}

bool can_send(can_data_t *hcan, struct gs_host_frame *frame) {
    CAN_TxMailBox_TypeDef *mb = can_find_free_mailbox(hcan);
    if (mb != 0) {

        /* first, clear transmission request */
        mb->TIR &= CAN_TI0R_TXRQ;

        if (frame->can_id & CAN_EFF_FLAG) { // extended id
            mb->TIR = CAN_ID_EXT | (frame->can_id & 0x1FFFFFFF) << 3;
        } else {
            mb->TIR = (frame->can_id & 0x7FF) << 21;
        }

        if (frame->can_id & CAN_RTR_FLAG) {
            mb->TIR |= CAN_RTR_REMOTE;
        }

        mb->TDTR &= 0xFFFFFFF0;
        mb->TDTR |= frame->can_dlc & 0x0F;

        mb->TDLR =
            (frame->data[3] << 24)
                | (frame->data[2] << 16)
                | (frame->data[1] << 8)
                | (frame->data[0] << 0);

        mb->TDHR =
            (frame->data[7] << 24)
                | (frame->data[6] << 16)
                | (frame->data[5] << 8)
                | (frame->data[4] << 0);

        /* request transmission */
        mb->TIR |= CAN_TI0R_TXRQ;

        return true;
    } else {
        return false;
    }
}

uint32_t can_get_error_status(can_data_t *hcan) {
    CAN_TypeDef *can = hcan->instance;
    return can->ESR;
}

static bool status_is_active(uint32_t err) {
    return !(err & (CAN_ESR_BOFF | CAN_ESR_EPVF));
}
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

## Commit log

2021-08-10 Add project files
    [USB2ANY.GBL, USB2ANY.GBO, USB2ANY.GBP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]
2021-08-10 Add develop tools in readme.md and image using in readme.
    [USB2CAN.PrjPcb, USB2CAN.SchDoc]
2021-08-10 add circuit design in readme
2021-08-10 Add key points of circuit design in Readme
2021-08-10 The chapter of circuit making is added in readme. The directory structure has been modified and new files are ready to be added.
    [USB2ANY.GBL, USB2ANY.GBO, USB2ANY.GBP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]
2021-08-10 rearrange files
    [USB2CAN.PrjPcb, USB2CAN.SchDoc]
2021-08-11 Add gerber files and bom
    [2CAN+2UART.csv, 4CAN.csv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]
2021-08-11 modify readme
    [4CAN&2UART.csv]
2021-08-12 add drill files
2021-10-04 Modify readme to mark error prone areas.
    [Gerber_BoardOutline.GKO, Gerber_BottomLayer.GBL, Gerber_BottomPasteMaskLayer.GBP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]
